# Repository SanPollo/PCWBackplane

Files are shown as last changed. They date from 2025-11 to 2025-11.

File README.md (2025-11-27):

# PCW Backplane

1. [Introduction](#introduction)
2. [Features](#features)
3. [Compatible Expansions](#compatible-expansions)
2. [WARNING](#warning)
3. [Licence](#licence)
3. [BOM](#bom)
4. [Cable Orientation](#cable-orientation)
5. [Changelog](#changelog)

<br />

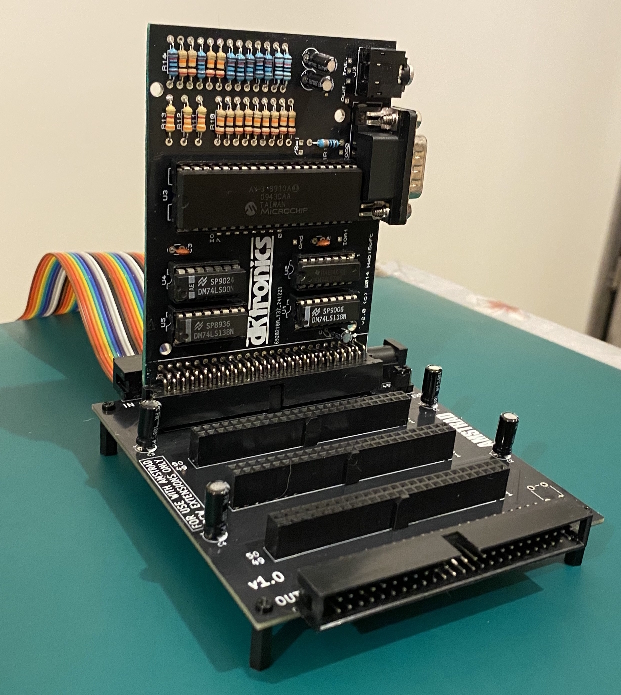
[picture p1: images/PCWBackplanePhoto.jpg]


<br />

## Introduction

PCW Backplane is an open source expansion backplane for the Amstrad PCW series of computers. It has been designed in such a way to allow existing expansion boards to be used without the need to modify them, as long as the edge connector is located at one end of the board.

The PCB is less than 100mm x 100mm, so it can be ordered cheaply from your favourite PCB manufacturer. I recommend [JLCPCB](https://jlcpcb.com/), and you can find the [gerbers here](gerbers/PCWBackplaneV1.1.zip). You can also find [this project on PCBWay](https://www.pcbway.com/project/shareproject/PCW_Backplane_7ff77698.html).

Inspired by [TotO](https://www.cpcwiki.eu/forum/profile/?u=290)'s MotherX4, and [revaldinho](https://github.com/revaldinho/)'s [MX4 expansion backplanes](https://github.com/revaldinho/cpc_ram_expansion/wiki/CPC-Expansion-Backplane) for the Amstrad CPC, it uses headers with the same number of pins. However, please read the [warning below](#warning).

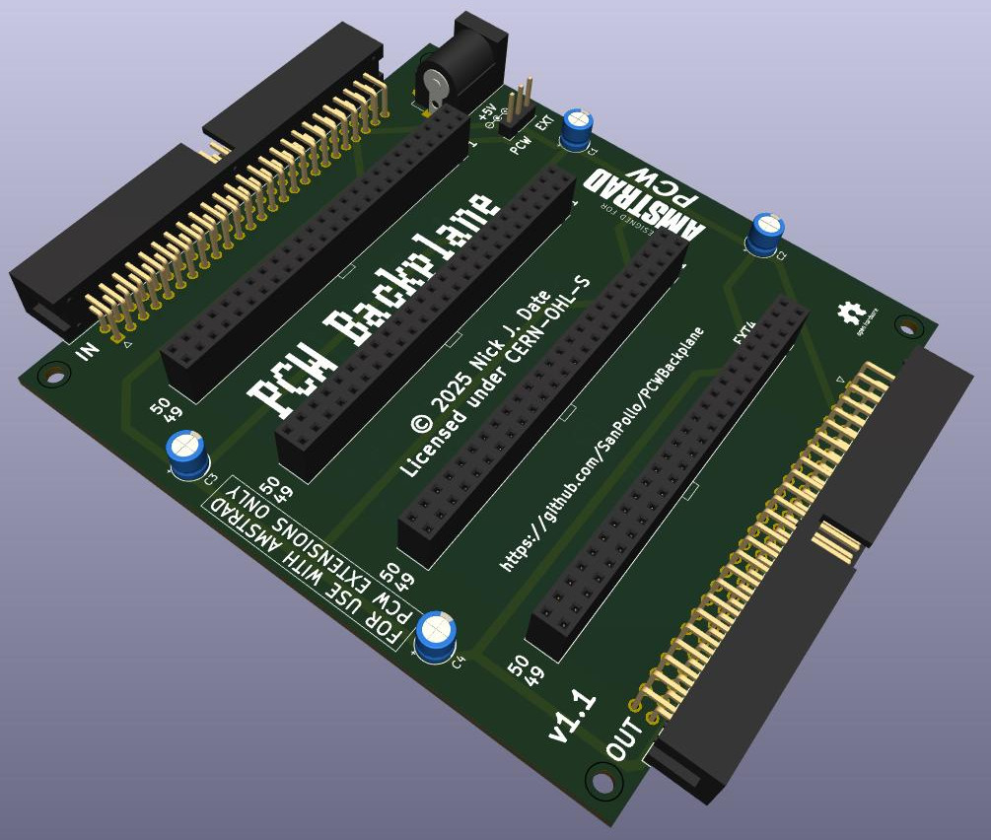
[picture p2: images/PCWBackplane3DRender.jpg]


<br />

## Features

- Allows up to four expansion boards to be connected to the computer.
- Has the same pin arrangement as the PCW's expansion edge connector so existing expansions can be connected without redesigning the board.
- Multiple backplanes can be daisy chained if need be.
- For 5V it can either use the PCW's internal power, or an optional external 5V power supply, should more current be required. 

<br />

## Compatible Expansions

As I test more expansions, I will add them this list. However, theoretically, any expansion should work without issue. If you have tested another expansion with the PCW Backplane, please raise an Issue letting me know, and I will update the list.

- [DK'tronics Sound & Joystick clone](https://www.habisoft.com/pcwwiki/doku.php?id=es:hardware:perifericos:dksound)

<br />

## WARNING

Despite using the same headers as MX4 backplanes, **the two are not compatible**.

The PCW and CPC ranges of computers share the same expansion edge connector, however the pinout is **very different**. Not only are the pins in different places, but the PCW also has a +12V pin.

**PLUGGING AN MX4 CARD INTO THIS BACKPLANE WILL ALMOST CERTAINLY DAMAGE THE EXPANSION CARD, AND MAY ALSO DAMAGE THE COMPUTER.**

<br />

## Licence

This project is licensed under the [CERN Open Hardware Licence Version 2: CERN-OHL-S](https://opensource.org/license/cern-ohl-s). If you intend to build and/or sell this PCB, make sure that you first read and understand the licence, as it also includes both a disclaimer of liability, and the terms under which you may use the project.

<br />

## BOM

| Ref | Qty | Part |
| --- | --- | ---- |
| +5V |  1  | Barrel Connector 90-deg 5.5mm x 2.1mm |
| C1, C2 | 2 | 22uF 16V electrolytic capacitor * |
| C3, C4 | 2 | 22uF 50V electrolytic capacitor * |
| EXT1, EXT2, EXT3, EXT4 | 4 | 2x25-pin **keyed** female header ** |
| IN, OUT | 2 | 2x25-pin 90-deg box header |
| CABLE | 2 | 2X25-pin IDC connector |
| CABLE | 1 | 50-pin ribbon cable |
| PCW EXT | 1 | 1x3-pin header |
| PCW EXT | 1 | Jumper |
| STANDOFFS | - | Appropriate M2-sized standoffs / spacers |

\* You can use 50V capacitors for C1 and C2 as well, but C3 and C4 are for the 12V line so they require at least 24V tolerance.

** **Do not use unkeyed headers.** They are much cheaper but you risk damaging the expansion, and the computer itself, if you accidentally plug an expansion in misaligned. I did this with an MX4 card in a CPC, and was very lucky that nothing bad happened. Keyed headers can be found on [AliExpress](https://www.aliexpress.com/).

<br />

## Cable Orientation

The photos below show the orientation of the cable. There will be a twist between the PCW and the backplane.

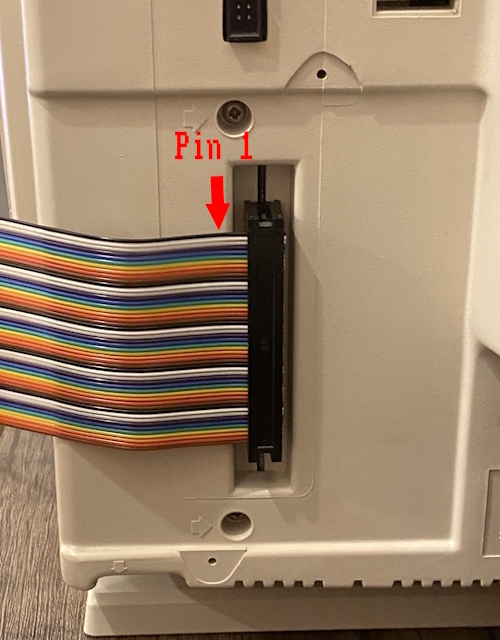
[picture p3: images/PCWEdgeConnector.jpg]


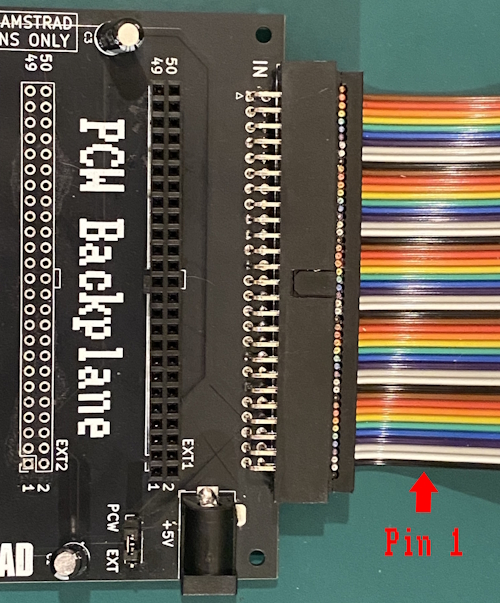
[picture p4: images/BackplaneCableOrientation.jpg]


<br />

## Changelog

### v1.1

Corrected the silkscreen for the EXT headers, removed the RESET button, and added the remaining silkscreen I had intended to previously.

### v1.0 (Unreleased)

Prototype, shown in the pictures, which had the silkscreen for the EXT headers the wrong way around and a RESET button. The RESET button was removed as the RESET line on the PCW's expansion connector is not connected to the pin on the Z80, but is instead a signal the the PCW sends to expansions when it is reset.

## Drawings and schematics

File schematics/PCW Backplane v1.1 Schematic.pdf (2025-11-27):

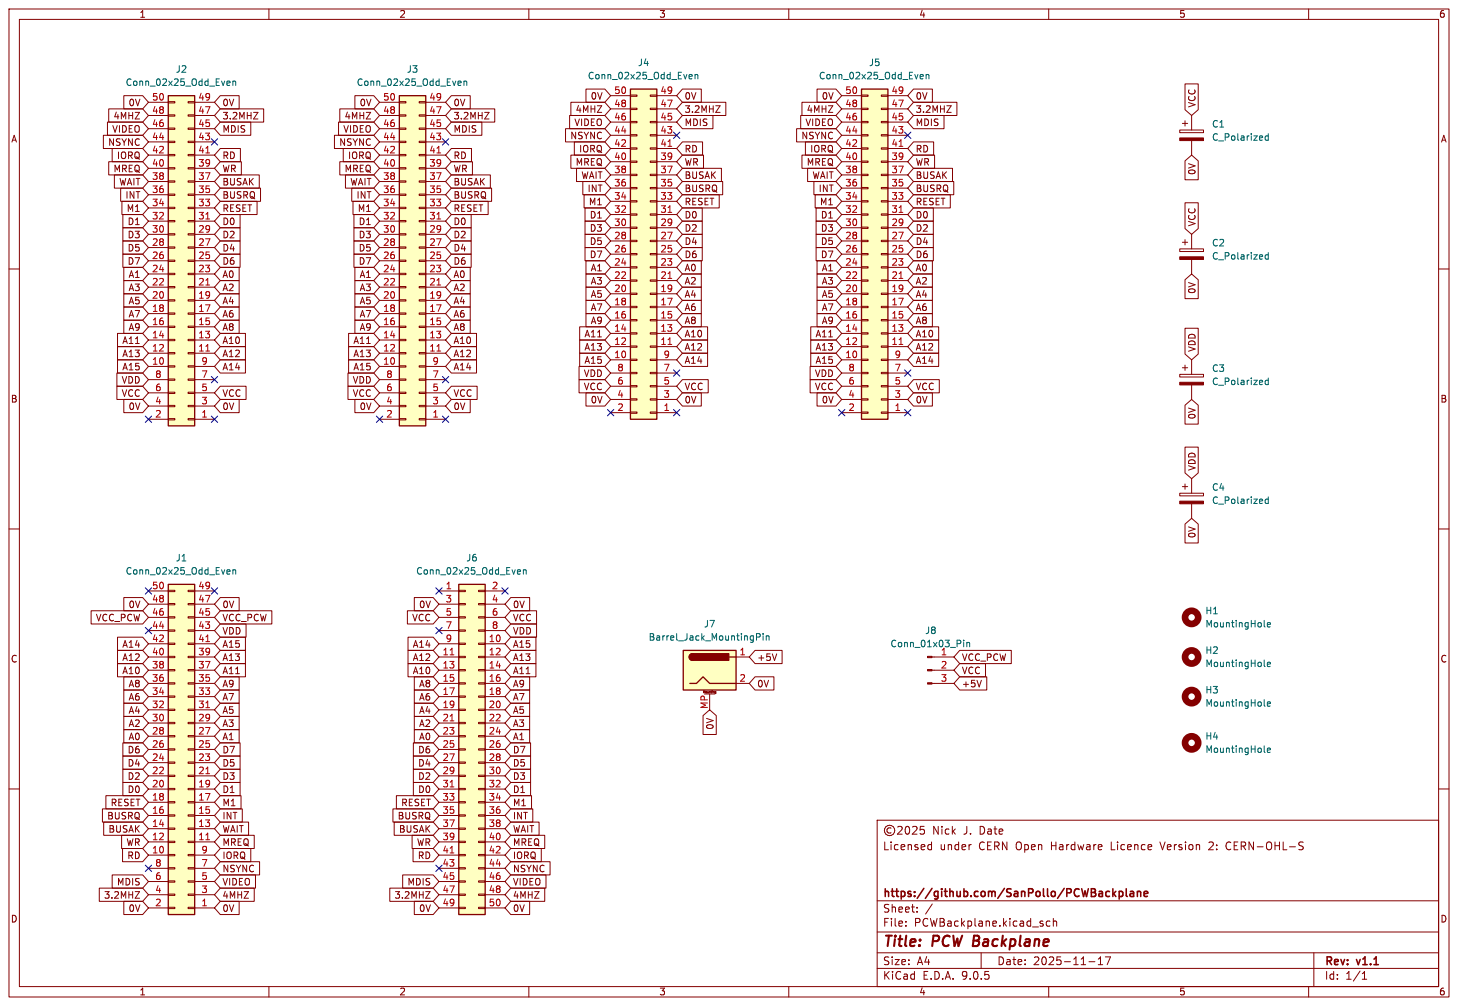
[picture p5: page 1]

File: PCWBackplane.kicad_sch Sheet: / https://github.com/SanPollo/PCWBackplane

Id: 1/1 Title: PCW Backplane

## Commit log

2025-10-24 Created gerbers folder
2025-10-24 Uploaded gerbers
2025-11-27 Add files via upload
    Added PDF version of the schematic
2026-05-13 Added silkscreen for pins 1 and 2 for IN and OUT
    The IN connector has a square pin, and an arrow pointing towards pin 50 instead of pin 1. Until I have got around to editing the symbol, I have added silkscreen to label pins 1 and 2 on both the IN and OUT connectors, which should avoid any confusion.
